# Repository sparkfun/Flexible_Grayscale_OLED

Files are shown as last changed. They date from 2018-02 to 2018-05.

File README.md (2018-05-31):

SparkFun Flexible Grayscale OLED Display Breakout Board
========================================

SparkFun Flexible Grayscale Carrier Board

[*SparkFun Flexible Grayscale Display - 1.81" (LCD-14606)*](https://www.sparkfun.com/products/14606)

This is a small flexible, grayscale OLED display. That’s right, we said flexible. We’ve been hearing about flexible displays for years, it’s finally here! You can’t fold it like paper but this OLED from Wisechip can be bent to a 40mm radius without damage. The display is than 0.5mm thick, less than 0.5 grams, and can display some impressive graphics with great contrast.

The carrier board generates the 12V required to drive the OLED display. The carrier board also has a signal buffer so that you can drive the display from any 3.3V or 5V microcontroller. However, because of the nature of the TXB0104 you must power the board with 3.5V or more. Your microcontroller can be 3.3V or 5V but we recommend you power the carrier board with 5V.

Repository Contents
-------------------

* **/Datasheets** - Datasheets explaining screen characteristics
* **/Hardware** - Eagle design files (.brd, .sch)
* **/Production** - Test bed files and production panel files.

Documentation
--------------
* **[Arduino Library](https://github.com/sparkfun/SparkFun_SSD1320_OLED_Arduino_Library)** - Arduino library for drawing, graphics, text, etc.
* **[BMP to Array](https://github.com/sparkfun/BMPtoArray)** - Python script to convert bitmaps to an Arduino prog_mem array when outputting grayscale images to OLEDs.
* **[Hookup Guide](https://learn.sparkfun.com/tutorials/flexible-grayscale-oled-hookup-guide)** - Basic hookup guide for the SparkFun Flexible Grayscale OLED Display.

License Information
-------------------

This product is _**open source**_! 

Please review the LICENSE.md file for license information. 

If you have any questions or concerns on licensing, please contact techsupport@sparkfun.com.

Please use, reuse, and modify these files as you see fit. Please maintain attribution to SparkFun Electronics and release anyThing Development Board derivative under the same license.

Distributed as-is; no warranty is given.

- Your friends at SparkFun.

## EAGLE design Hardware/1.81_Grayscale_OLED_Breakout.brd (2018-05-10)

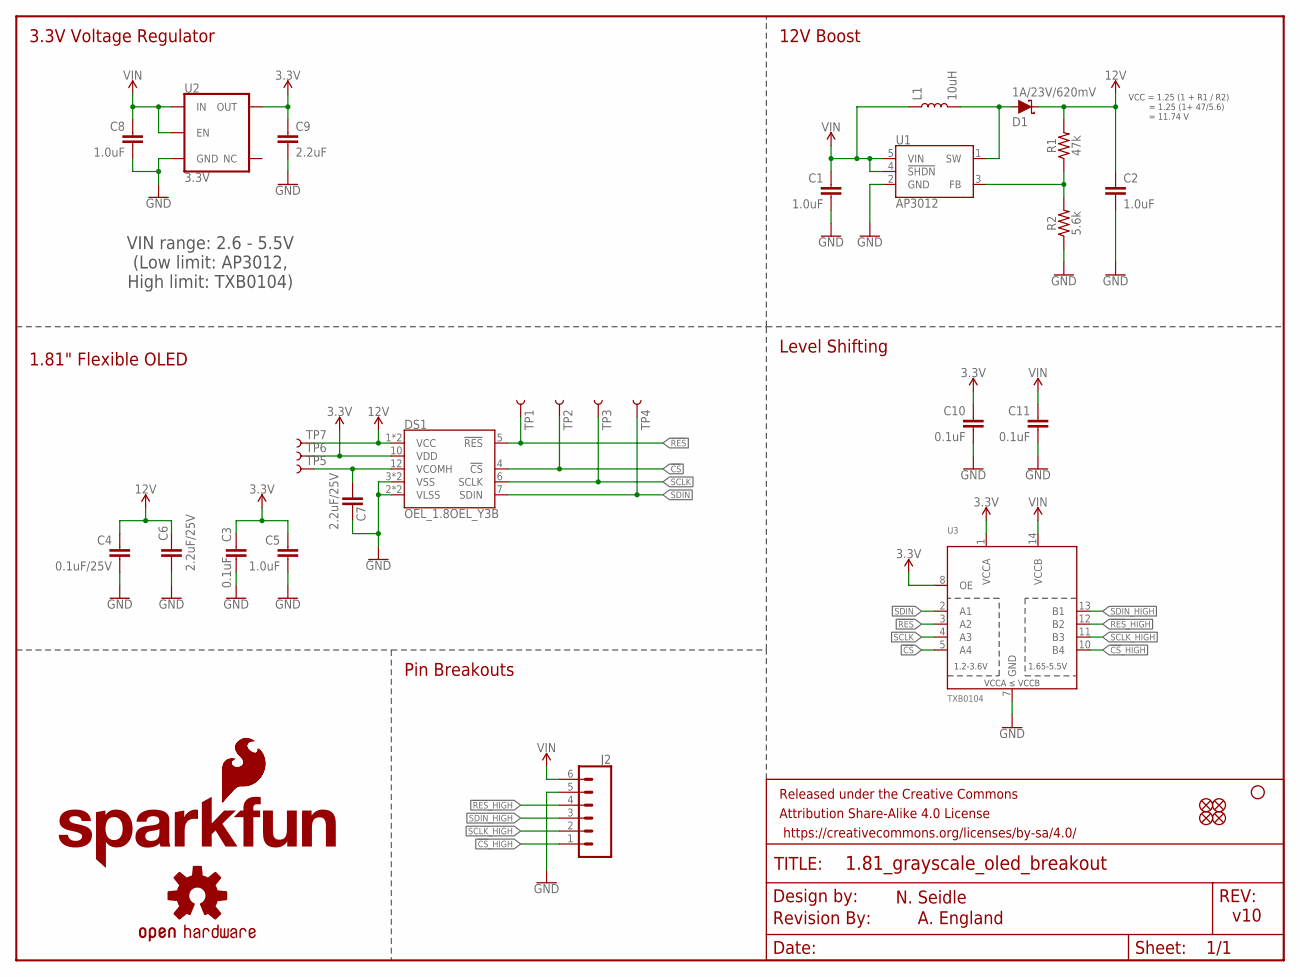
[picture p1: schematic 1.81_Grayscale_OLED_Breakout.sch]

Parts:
C1, C5, C8: 1.0uF; 0603
C2: 1.0uF; 0805
C3, C10, C11: 0.1uF; 0603
C4: 0.1uF/25V; 0603
C6, C7: 2.2uF/25V; 0805
C9: 2.2uF; 0603
D1: 1A/23V/620mV; SOD-323
DS1: OEL_1.8OEL_Y3B; OEL_1.8_FPC_Y3B
FD1, FD2, FD3, FD4: FIDUCIAL1X2; FIDUCIAL-1X2
FRAME1: FRAME-LETTER; CREATIVE_COMMONS
H2: STAND-OFF
J2: CONN_06NO_SILK_NO_POP; 1X06_NO_SILK
L1: 10uH; INDUCTOR_4.7UH
LOGO1: SFE_LOGO_NAME_FLAME.1_INCH; SFE_LOGO_NAME_FLAME_.1
LOGO2: REVISION
LOGO3: SFE_LOGO_FLAME.1_INCH; SFE_LOGO_FLAME_.1
LOGO4: OSHW-LOGOS; OSHW-LOGO-S
R1: 47k; 0603
R2: 5.6k; 0603
TP1, TP2, TP3, TP4, TP5, TP6, TP7: TEST-POINT3; PAD.03X.03
U1: AP3012; SOT23-5
U2: 3.3V; SOT23-5
U3: TXB0104; SO14

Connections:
3.3V: C3.1, C5.1, C9.1, C10.1, DS1.10 (VDD), TP6.P$1, U2.5 (OUT), U3.1 (VCCA), U3.8 (OE)
12V: C2.1, C4.1, C6.1, D1.C, DS1.1 (VCC), DS1.13 (VCC), R1.2, TP7.P$1
!CS!: DS1.4 (!CS!), TP2.P$1, U3.5 (A4)
!CS!_HIGH: J2.1, U3.10 (B4)
!RES!: DS1.5 (!RES!), TP1.P$1, U3.3 (A2)
!RES!_HIGH: J2.4, U3.12 (B2)
GND: C1.2, C2.2, C3.2, C4.2, C5.2, C6.2, C7.1, C8.2, C9.2, C10.2, C11.2, DS1.2 (VLSS), DS1.3 (VSS), DS1.8 (VSS), DS1.9 (VLSS), J2.5, R2.1, U1.2 (GND), U2.2 (GND), U3.7 (GND)
unnamed: C7.2, DS1.12 (VCOMH), TP5.P$1
unnamed: D1.A, L1.P$2 (2), U1.1 (SW)
unnamed: R1.1, R2.2, U1.3 (FB)
SCLK: DS1.6 (SCLK), TP3.P$1, U3.4 (A3)
SCLK_HIGH: J2.2, U3.11 (B3)
SDIN: DS1.7 (SDIN), TP4.P$1, U3.2 (A1)
SDIN_HIGH: J2.3, U3.13 (B1)
VIN: C1.1, C8.1, C11.1, J2.6, L1.P$1 (1), U1.4 (!SHDN!), U1.5 (VIN), U2.1 (IN), U2.3 (EN), U3.14 (VCCB)

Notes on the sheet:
VCC = 1.25 (1 + R1 / R2) = 1.25 (1+ 47/5.6) = 11.74 V
VIN range: 2.6 - 5.5V (Low limit: AP3012, High limit: TXB0104)
3.3V Voltage Regulator
12V Boost
1.81" Flexible OLED
Level Shifting
Pin Breakouts
v10
N. Seidle
A. England

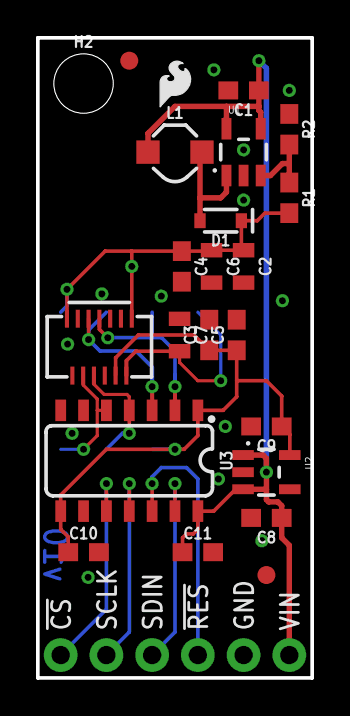
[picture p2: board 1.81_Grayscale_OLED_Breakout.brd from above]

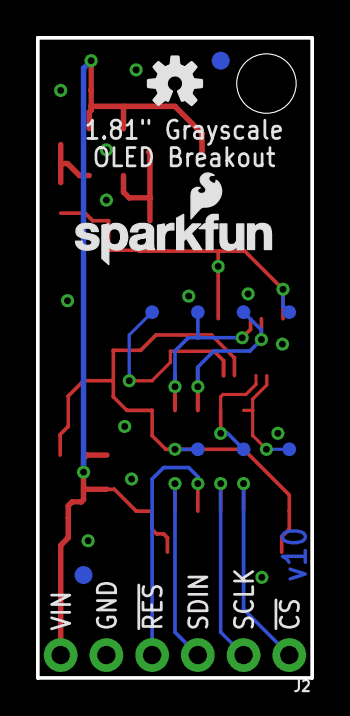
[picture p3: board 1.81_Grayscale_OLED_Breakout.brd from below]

Board: 2 copper layers, 15.2 x 35.6 mm, 37 parts (13 on the bottom side), 15 nets.

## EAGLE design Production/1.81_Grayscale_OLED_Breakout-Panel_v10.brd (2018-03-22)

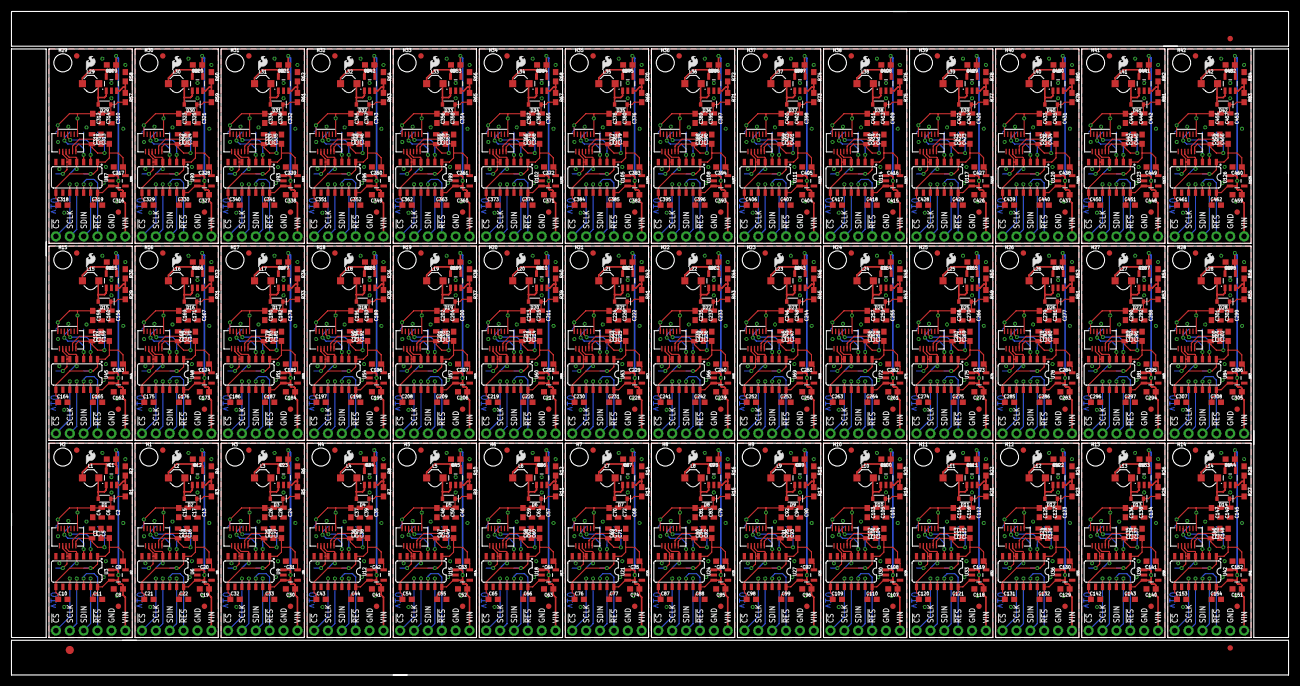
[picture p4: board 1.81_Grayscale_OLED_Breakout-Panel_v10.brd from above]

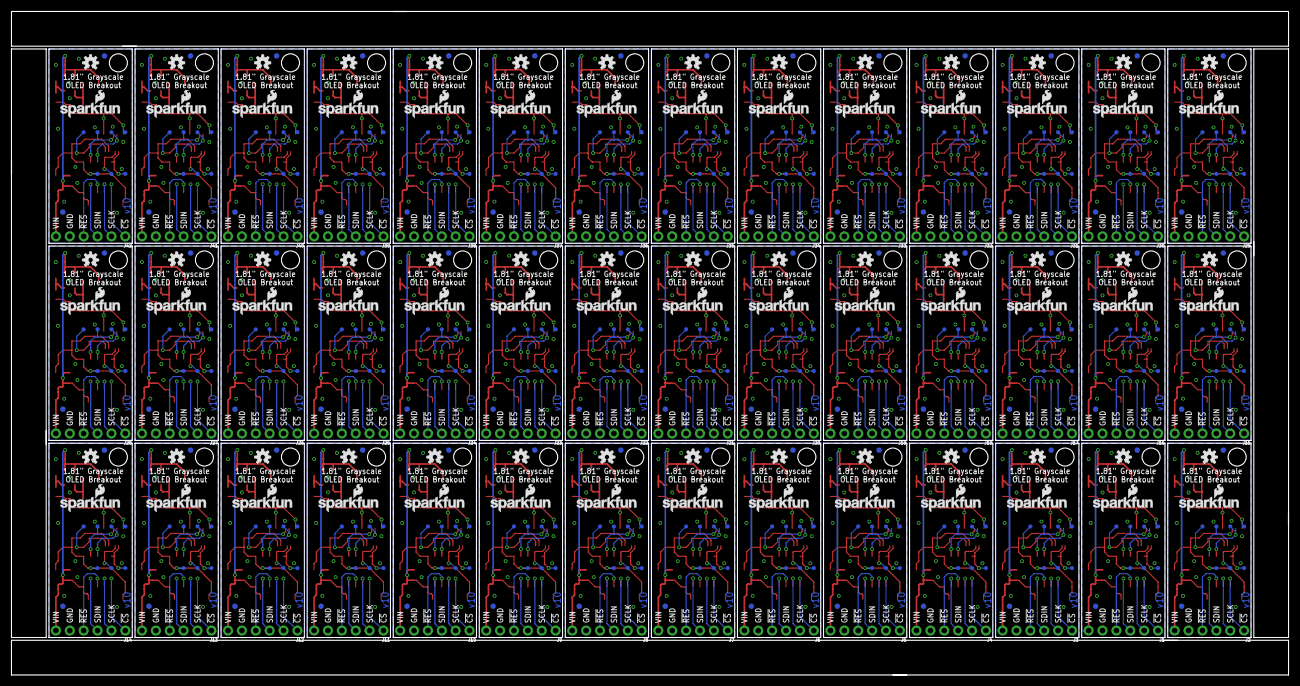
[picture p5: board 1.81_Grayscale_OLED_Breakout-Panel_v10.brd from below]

Board: 2 copper layers, 233.7 x 121.4 mm, 1473 parts (546 on the bottom side), 630 nets.

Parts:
C1, C5, C8, C12, C16, C19, C23, C27, C30, C34, C38, C41, C45, C49, C52, C56, C60, C63, C67, C71, C74, C78, C82, C85, C89, C93, C96, C100, C104, C107, C111, C115, C118, C122, C126, C129, C133, C137, C140, C144, C148, C151, C155, C159, C162, C166, C170, C173, C177, C181, C184, C188, C192, C195, C199, C203, C206, C210, C214, C217, C221, C225, C228, C232, C236, C239, C243, C247, C250, C254, C258, C261, C265, C269, C272, C276, C280, C283, C287, C291, C294, C298, C302, C305, C309, C313, C316, C320, C324, C327, C331, C335, C338, C342, C346, C349, C353, C357, C360, C364, C368, C371, C375, C379, C382, C386, C390, C393, C397, C401, C404, C408, C412, C415, C419, C423, C426, C430, C434, C437, C441, C445, C448, C452, C456, C459: 1.0uF; 0603
C2, C13, C24, C35, C46, C57, C68, C79, C90, C101, C112, C123, C134, C145, C156, C167, C178, C189, C200, C211, C222, C233, C244, C255, C266, C277, C288, C299, C310, C321, C332, C343, C354, C365, C376, C387, C398, C409, C420, C431, C442, C453: 1.0uF; 0805
C3, C10, C11, C14, C21, C22, C25, C32, C33, C36, C43, C44, C47, C54, C55, C58, C65, C66, C69, C76, C77, C80, C87, C88, C91, C98, C99, C102, C109, C110, C113, C120, C121, C124, C131, C132, C135, C142, C143, C146, C153, C154, C157, C164, C165, C168, C175, C176, C179, C186, C187, C190, C197, C198, C201, C208, C209, C212, C219, C220, C223, C230, C231, C234, C241, C242, C245, C252, C253, C256, C263, C264, C267, C274, C275, C278, C285, C286, C289, C296, C297, C300, C307, C308, C311, C318, C319, C322, C329, C330, C333, C340, C341, C344, C351, C352, C355, C362, C363, C366, C373, C374, C377, C384, C385, C388, C395, C396, C399, C406, C407, C410, C417, C418, C421, C428, C429, C432, C439, C440, C443, C450, C451, C454, C461, C462: 0.1uF; 0603
C4, C15, C26, C37, C48, C59, C70, C81, C92, C103, C114, C125, C136, C147, C158, C169, C180, C191, C202, C213, C224, C235, C246, C257, C268, C279, C290, C301, C312, C323, C334, C345, C356, C367, C378, C389, C400, C411, C422, C433, C444, C455: 0.1uF/25V; 0603
C6, C7, C17, C18, C28, C29, C39, C40, C50, C51, C61, C62, C72, C73, C83, C84, C94, C95, C105, C106, C116, C117, C127, C128, C138, C139, C149, C150, C160, C161, C171, C172, C182, C183, C193, C194, C204, C205, C215, C216, C226, C227, C237, C238, C248, C249, C259, C260, C270, C271, C281, C282, C292, C293, C303, C304, C314, C315, C325, C326, C336, C337, C347, C348, C358, C359, C369, C370, C380, C381, C391, C392, C402, C403, C413, C414, C424, C425, C435, C436, C446, C447, C457, C458: 2.2uF/25V; 0805
C9, C20, C31, C42, C53, C64, C75, C86, C97, C108, C119, C130, C141, C152, C163, C174, C185, C196, C207, C218, C229, C240, C251, C262, C273, C284, C295, C306, C317, C328, C339, C350, C361, C372, C383, C394, C405, C416, C427, C438, C449, C460: 2.2uF; 0603
D1, D2, D3, D4, D5, D6, D7, D8, D9, D10, D11, D12, D13, D14, D15, D16, D17, D18, D19, D20, D21, D22, D23, D24, D25, D26, D27, D28, D29, D30, D31, D32, D33, D34, D35, D36, D37, D38, D39, D40, D41, D42: 1A/23V/620mV; SOD-323
DS1, DS2, DS3, DS4, DS5, DS6, DS7, DS8, DS9, DS10, DS11, DS12, DS13, DS14, DS15, DS16, DS17, DS18, DS19, DS20, DS21, DS22, DS23, DS24, DS25, DS26, DS27, DS28, DS29, DS30, DS31, DS32, DS33, DS34, DS35, DS36, DS37, DS38, DS39, DS40, DS41, DS42: OEL_1.8OEL_Y3B; OEL_1.8_FPC_Y3B
E$1: FIDUCIAL-1.5X3
E$5, E$6: FIDUCIAL-1X2
FD1, FD2, FD3, FD4, FD5, FD6, FD7, FD8, FD9, FD10, FD11, FD12, FD13, FD14, FD15, FD16, FD17, FD18, FD19, FD20, FD21, FD22, FD23, FD24, FD25, FD26, FD27, FD28, FD29, FD30, FD31, FD32, FD33, FD34, FD35, FD36, FD37, FD38, FD39, FD40, FD41, FD42, FD43, FD44, FD45, FD46, FD47, FD48, FD49, FD50, FD51, FD52, FD53, FD54, FD55, FD56, FD57, FD58, FD59, FD60, FD61, FD62, FD63, FD64, FD65, FD66, FD67, FD68, FD69, FD70, FD71, FD72, FD73, FD74, FD75, FD76, FD77, FD78, FD79, FD80, FD81, FD82, FD83, FD84, FD85, FD86, FD87, FD88, FD89, FD90, FD91, FD92, FD93, FD94, FD95, FD96, FD97, FD98, FD99, FD100, FD101, FD102, FD103, FD104, FD105, FD106, FD107, FD108, FD109, FD110, FD111, FD112, FD113, FD114, FD115, FD116, FD117, FD118, FD119, FD120, FD121, FD122, FD123, FD124, FD125, FD126, FD127, FD128, FD129, FD130, FD131, FD132, FD133, FD134, FD135, FD136, FD137, FD138, FD139, FD140, FD141, FD142, FD143, FD144, FD145, FD146, FD147, FD148, FD149, FD150, FD151, FD152, FD153, FD154, FD155, FD156, FD157, FD158, FD159, FD160, FD161, FD162, FD163, FD164, FD165, FD166, FD167, FD168: FIDUCIAL1X2; FIDUCIAL-1X2
H1, H2, H3, H4, H5, H6, H7, H8, H9, H10, H11, H12, H13, H14, H15, H16, H17, H18, H19, H20, H21, H22, H23, H24, H25, H26, H27, H28, H29, H30, H31, H32, H33, H34, H35, H36, H37, H38, H39, H40, H41, H42: STAND-OFF
J1, J2, J3, J4, J5, J6, J7, J8, J9, J10, J11, J12, J13, J14, J15, J16, J17, J18, J19, J20, J21, J22, J23, J24, J25, J26, J27, J28, J29, J30, J31, J32, J33, J34, J35, J36, J37, J38, J39, J40, J41, J42: 1X06_NO_SILK
L1, L2, L3, L4, L5, L6, L7, L8, L9, L10, L11, L12, L13, L14, L15, L16, L17, L18, L19, L20, L21, L22, L23, L24, L25, L26, L27, L28, L29, L30, L31, L32, L33, L34, L35, L36, L37, L38, L39, L40, L41, L42: 10uH; INDUCTOR_4.7UH
LOGO1, LOGO2, LOGO7, LOGO10, LOGO13, LOGO16, LOGO19, LOGO22, LOGO25, LOGO28, LOGO31, LOGO34, LOGO37, LOGO40, LOGO43, LOGO46, LOGO49, LOGO52, LOGO55, LOGO58, LOGO61, LOGO64, LOGO67, LOGO70, LOGO73, LOGO76, LOGO79, LOGO82, LOGO85, LOGO88, LOGO91, LOGO94, LOGO97, LOGO100, LOGO103, LOGO106, LOGO109, LOGO112, LOGO115, LOGO118, LOGO121, LOGO124: SFE_LOGO_NAME_FLAME.1_INCH; SFE_LOGO_NAME_FLAME_.1
LOGO3, LOGO5, LOGO8, LOGO11, LOGO14, LOGO17, LOGO20, LOGO23, LOGO26, LOGO29, LOGO32, LOGO35, LOGO38, LOGO41, LOGO44, LOGO47, LOGO50, LOGO53, LOGO56, LOGO59, LOGO62, LOGO65, LOGO68, LOGO71, LOGO74, LOGO77, LOGO80, LOGO83, LOGO86, LOGO89, LOGO92, LOGO95, LOGO98, LOGO101, LOGO104, LOGO107, LOGO110, LOGO113, LOGO116, LOGO119, LOGO122, LOGO125: SFE_LOGO_FLAME.1_INCH; SFE_LOGO_FLAME_.1
LOGO4, LOGO6, LOGO9, LOGO12, LOGO15, LOGO18, LOGO21, LOGO24, LOGO27, LOGO30, LOGO33, LOGO36, LOGO39, LOGO42, LOGO45, LOGO48, LOGO51, LOGO54, LOGO57, LOGO60, LOGO63, LOGO66, LOGO69, LOGO72, LOGO75, LOGO78, LOGO81, LOGO84, LOGO87, LOGO90, LOGO93, LOGO96, LOGO99, LOGO102, LOGO105, LOGO108, LOGO111, LOGO114, LOGO117, LOGO120, LOGO123, LOGO126: OSHW-LOGOS; OSHW-LOGO-S
R1, R3, R5, R7, R9, R11, R13, R15, R17, R19, R21, R23, R25, R27, R29, R31, R33, R35, R37, R39, R41, R43, R45, R47, R49, R51, R53, R55, R57, R59, R61, R63, R65, R67, R69, R71, R73, R75, R77, R79, R81, R83: 47k; 0603
R2, R4, R6, R8, R10, R12, R14, R16, R18, R20, R22, R24, R26, R28, R30, R32, R34, R36, R38, R40, R42, R44, R46, R48, R50, R52, R54, R56, R58, R60, R62, R64, R66, R68, R70, R72, R74, R76, R78, R80, R82, R84: 5.6k; 0603
TP1, TP2, TP3, TP4, TP5, TP6, TP7, TP8, TP9, TP10, TP11, TP12, TP13, TP14, TP15, TP16, TP17, TP18, TP19, TP20, TP21, TP22, TP23, TP24, TP25, TP26, TP27, TP28, TP29, TP30, TP31, TP32, TP33, TP34, TP35, TP36, TP37, TP38, TP39, TP40, TP41, TP42, TP43, TP44, TP45, TP46, TP47, TP48, TP49, TP50, TP51, TP52, TP53, TP54, TP55, TP56, TP57, TP58, TP59, TP60, TP61, TP62, TP63, TP64, TP65, TP66, TP67, TP68, TP69, TP70, TP71, TP72, TP73, TP74, TP75, TP76, TP77, TP78, TP79, TP80, TP81, TP82, TP83, TP84, TP85, TP86, TP87, TP88, TP89, TP90, TP91, TP92, TP93, TP94, TP95, TP96, TP97, TP98, TP99, TP100, TP101, TP102, TP103, TP104, TP105, TP106, TP107, TP108, TP109, TP110, TP111, TP112, TP113, TP114, TP115, TP116, TP117, TP118, TP119, TP120, TP121, TP122, TP123, TP124, TP125, TP126, TP127, TP128, TP129, TP130, TP131, TP132, TP133, TP134, TP135, TP136, TP137, TP138, TP139, TP140, TP141, TP142, TP143, TP144, TP145, TP146, TP147, TP148, TP149, TP150, TP151, TP152, TP153, TP154, TP155, TP156, TP157, TP158, TP159, TP160, TP161, TP162, TP163, TP164, TP165, TP166, TP167, TP168, TP169, TP170, TP171, TP172, TP173, TP174, TP175, TP176, TP177, TP178, TP179, TP180, TP181, TP182, TP183, TP184, TP185, TP186, TP187, TP188, TP189, TP190, TP191, TP192, TP193, TP194, TP195, TP196, TP197, TP198, TP199, TP200, TP201, TP202, TP203, TP204, TP205, TP206, TP207, TP208, TP209, TP210, TP211, TP212, TP213, TP214, TP215, TP216, TP217, TP218, TP219, TP220, TP221, TP222, TP223, TP224, TP225, TP226, TP227, TP228, TP229, TP230, TP231, TP232, TP233, TP234, TP235, TP236, TP237, TP238, TP239, TP240, TP241, TP242, TP243, TP244, TP245, TP246, TP247, TP248, TP249, TP250, TP251, TP252, TP253, TP254, TP255, TP256, TP257, TP258, TP259, TP260, TP261, TP262, TP263, TP264, TP265, TP266, TP267, TP268, TP269, TP270, TP271, TP272, TP273, TP274, TP275, TP276, TP277, TP278, TP279, TP280, TP281, TP282, TP283, TP284, TP285, TP286, TP287, TP288, TP289, TP290, TP291, TP292, TP293, TP294: TEST-POINT3; PAD.03X.03
U1, U4, U7, U10, U13, U16, U19, U22, U25, U28, U31, U34, U37, U40, U43, U46, U49, U52, U55, U58, U61, U64, U67, U70, U73, U76, U79, U82, U85, U88, U91, U94, U97, U100, U103, U106, U109, U112, U115, U118, U121, U124: AP3012; SOT23-5
U2, U5, U8, U11, U14, U17, U20, U23, U26, U29, U32, U35, U38, U41, U44, U47, U50, U53, U56, U59, U62, U65, U68, U71, U74, U77, U80, U83, U86, U89, U92, U95, U98, U101, U104, U107, U110, U113, U116, U119, U122, U125: 3.3V; SOT23-5
U3, U6, U9, U12, U15, U18, U21, U24, U27, U30, U33, U36, U39, U42, U45, U48, U51, U54, U57, U60, U63, U66, U69, U72, U75, U78, U81, U84, U87, U90, U93, U96, U99, U102, U105, U108, U111, U114, U117, U120, U123, U126: TXB0104; SO14

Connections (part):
3.3V: C3.1, C5.1, C9.1, C10.1, DS1.10, TP6.P$1, U2.5, U3.1, U3.8
3.3V1: C14.1, C16.1, C20.1, C21.1, DS2.10, TP13.P$1, U5.5, U6.1, U6.8
3.3V2: C25.1, C27.1, C31.1, C32.1, DS3.10, TP20.P$1, U8.5, U9.1, U9.8
3.3V3: C36.1, C38.1, C42.1, C43.1, DS4.10, TP27.P$1, U11.5, U12.1, U12.8
3.3V4: C47.1, C49.1, C53.1, C54.1, DS5.10, TP34.P$1, U14.5, U15.1, U15.8
3.3V5: C58.1, C60.1, C64.1, C65.1, DS6.10, TP41.P$1, U17.5, U18.1, U18.8
3.3V6: C69.1, C71.1, C75.1, C76.1, DS7.10, TP48.P$1, U20.5, U21.1, U21.8
3.3V7: C80.1, C82.1, C86.1, C87.1, DS8.10, TP55.P$1, U23.5, U24.1, U24.8
3.3V8: C91.1, C93.1, C97.1, C98.1, DS9.10, TP62.P$1, U26.5, U27.1, U27.8
3.3V9: C102.1, C104.1, C108.1, C109.1, DS10.10, TP69.P$1, U29.5, U30.1, U30.8
3.3V10: C113.1, C115.1, C119.1, C120.1, DS11.10, TP76.P$1, U32.5, U33.1, U33.8
3.3V11: C124.1, C126.1, C130.1, C131.1, DS12.10, TP83.P$1, U35.5, U36.1, U36.8
3.3V12: C135.1, C137.1, C141.1, C142.1, DS13.10, TP90.P$1, U38.5, U39.1, U39.8
3.3V13: C146.1, C148.1, C152.1, C153.1, DS14.10, TP97.P$1, U41.5, U42.1, U42.8
3.3V14: C157.1, C159.1, C163.1, C164.1, DS15.10, TP104.P$1, U44.5, U45.1, U45.8
3.3V15: C168.1, C170.1, C174.1, C175.1, DS16.10, TP111.P$1, U47.5, U48.1, U48.8
3.3V16: C179.1, C181.1, C185.1, C186.1, DS17.10, TP118.P$1, U50.5, U51.1, U51.8
3.3V17: C190.1, C192.1, C196.1, C197.1, DS18.10, TP125.P$1, U53.5, U54.1, U54.8
3.3V18: C201.1, C203.1, C207.1, C208.1, DS19.10, TP132.P$1, U56.5, U57.1, U57.8
3.3V19: C212.1, C214.1, C218.1, C219.1, DS20.10, TP139.P$1, U59.5, U60.1, U60.8
3.3V20: C223.1, C225.1, C229.1, C230.1, DS21.10, TP146.P$1, U62.5, U63.1, U63.8
3.3V21: C234.1, C236.1, C240.1, C241.1, DS22.10, TP153.P$1, U65.5, U66.1, U66.8
3.3V22: C245.1, C247.1, C251.1, C252.1, DS23.10, TP160.P$1, U68.5, U69.1, U69.8
3.3V23: C256.1, C258.1, C262.1, C263.1, DS24.10, TP167.P$1, U71.5, U72.1, U72.8
3.3V24: C267.1, C269.1, C273.1, C274.1, DS25.10, TP174.P$1, U74.5, U75.1, U75.8
3.3V25: C278.1, C280.1, C284.1, C285.1, DS26.10, TP181.P$1, U77.5, U78.1, U78.8
3.3V26: C289.1, C291.1, C295.1, C296.1, DS27.10, TP188.P$1, U80.5, U81.1, U81.8
3.3V27: C300.1, C302.1, C306.1, C307.1, DS28.10, TP195.P$1, U83.5, U84.1, U84.8
3.3V28: C311.1, C313.1, C317.1, C318.1, DS29.10, TP202.P$1, U86.5, U87.1, U87.8
3.3V29: C322.1, C324.1, C328.1, C329.1, DS30.10, TP209.P$1, U89.5, U90.1, U90.8
3.3V30: C333.1, C335.1, C339.1, C340.1, DS31.10, TP216.P$1, U92.5, U93.1, U93.8
3.3V31: C344.1, C346.1, C350.1, C351.1, DS32.10, TP223.P$1, U95.5, U96.1, U96.8
3.3V32: C355.1, C357.1, C361.1, C362.1, DS33.10, TP230.P$1, U98.5, U99.1, U99.8
3.3V33: C366.1, C368.1, C372.1, C373.1, DS34.10, TP237.P$1, U101.5, U102.1, U102.8
3.3V34: C377.1, C379.1, C383.1, C384.1, DS35.10, TP244.P$1, U104.5, U105.1, U105.8
3.3V35: C388.1, C390.1, C394.1, C395.1, DS36.10, TP251.P$1, U107.5, U108.1, U108.8
3.3V36: C399.1, C401.1, C405.1, C406.1, DS37.10, TP258.P$1, U110.5, U111.1, U111.8
3.3V37: C410.1, C412.1, C416.1, C417.1, DS38.10, TP265.P$1, U113.5, U114.1, U114.8
3.3V38: C421.1, C423.1, C427.1, C428.1, DS39.10, TP272.P$1, U116.5, U117.1, U117.8
3.3V39: C432.1, C434.1, C438.1, C439.1, DS40.10, TP279.P$1, U119.5, U120.1, U120.8
3.3V40: C443.1, C445.1, C449.1, C450.1, DS41.10, TP286.P$1, U122.5, U123.1, U123.8
3.3V41: C454.1, C456.1, C460.1, C461.1, DS42.10, TP293.P$1, U125.5, U126.1, U126.8
12V: C2.1, C4.1, C6.1, D1.C, DS1.1, DS1.13, R1.2, TP7.P$1
12V1: C13.1, C15.1, C17.1, D2.C, DS2.1, DS2.13, R3.2, TP14.P$1
12V2: C24.1, C26.1, C28.1, D3.C, DS3.1, DS3.13, R5.2, TP21.P$1
12V3: C35.1, C37.1, C39.1, D4.C, DS4.1, DS4.13, R7.2, TP28.P$1
12V4: C46.1, C48.1, C50.1, D5.C, DS5.1, DS5.13, R9.2, TP35.P$1
12V5: C57.1, C59.1, C61.1, D6.C, DS6.1, DS6.13, R11.2, TP42.P$1
12V6: C68.1, C70.1, C72.1, D7.C, DS7.1, DS7.13, R13.2, TP49.P$1
12V7: C79.1, C81.1, C83.1, D8.C, DS8.1, DS8.13, R15.2, TP56.P$1
12V8: C90.1, C92.1, C94.1, D9.C, DS9.1, DS9.13, R17.2, TP63.P$1
12V9: C101.1, C103.1, C105.1, D10.C, DS10.1, DS10.13, R19.2, TP70.P$1
12V10: C112.1, C114.1, C116.1, D11.C, DS11.1, DS11.13, R21.2, TP77.P$1
12V11: C123.1, C125.1, C127.1, D12.C, DS12.1, DS12.13, R23.2, TP84.P$1
12V12: C134.1, C136.1, C138.1, D13.C, DS13.1, DS13.13, R25.2, TP91.P$1
12V13: C145.1, C147.1, C149.1, D14.C, DS14.1, DS14.13, R27.2, TP98.P$1
12V14: C156.1, C158.1, C160.1, D15.C, DS15.1, DS15.13, R29.2, TP105.P$1
12V15: C167.1, C169.1, C171.1, D16.C, DS16.1, DS16.13, R31.2, TP112.P$1
12V16: C178.1, C180.1, C182.1, D17.C, DS17.1, DS17.13, R33.2, TP119.P$1
12V17: C189.1, C191.1, C193.1, D18.C, DS18.1, DS18.13, R35.2, TP126.P$1
12V18: C200.1, C202.1, C204.1, D19.C, DS19.1, DS19.13, R37.2, TP133.P$1
12V19: C211.1, C213.1, C215.1, D20.C, DS20.1, DS20.13, R39.2, TP140.P$1
12V20: C222.1, C224.1, C226.1, D21.C, DS21.1, DS21.13, R41.2, TP147.P$1
12V21: C233.1, C235.1, C237.1, D22.C, DS22.1, DS22.13, R43.2, TP154.P$1
12V22: C244.1, C246.1, C248.1, D23.C, DS23.1, DS23.13, R45.2, TP161.P$1
12V23: C255.1, C257.1, C259.1, D24.C, DS24.1, DS24.13, R47.2, TP168.P$1
12V24: C266.1, C268.1, C270.1, D25.C, DS25.1, DS25.13, R49.2, TP175.P$1
12V25: C277.1, C279.1, C281.1, D26.C, DS26.1, DS26.13, R51.2, TP182.P$1
12V26: C288.1, C290.1, C292.1, D27.C, DS27.1, DS27.13, R53.2, TP189.P$1
12V27: C299.1, C301.1, C303.1, D28.C, DS28.1, DS28.13, R55.2, TP196.P$1
12V28: C310.1, C312.1, C314.1, D29.C, DS29.1, DS29.13, R57.2, TP203.P$1
12V29: C321.1, C323.1, C325.1, D30.C, DS30.1, DS30.13, R59.2, TP210.P$1
12V30: C332.1, C334.1, C336.1, D31.C, DS31.1, DS31.13, R61.2, TP217.P$1
12V31: C343.1, C345.1, C347.1, D32.C, DS32.1, DS32.13, R63.2, TP224.P$1
12V32: C354.1, C356.1, C358.1, D33.C, DS33.1, DS33.13, R65.2, TP231.P$1
12V33: C365.1, C367.1, C369.1, D34.C, DS34.1, DS34.13, R67.2, TP238.P$1
12V34: C376.1, C378.1, C380.1, D35.C, DS35.1, DS35.13, R69.2, TP245.P$1
12V35: C387.1, C389.1, C391.1, D36.C, DS36.1, DS36.13, R71.2, TP252.P$1
12V36: C398.1, C400.1, C402.1, D37.C, DS37.1, DS37.13, R73.2, TP259.P$1
12V37: C409.1, C411.1, C413.1, D38.C, DS38.1, DS38.13, R75.2, TP266.P$1
12V38: C420.1, C422.1, C424.1, D39.C, DS39.1, DS39.13, R77.2, TP273.P$1
12V39: C431.1, C433.1, C435.1, D40.C, DS40.1, DS40.13, R79.2, TP280.P$1
12V40: C442.1, C444.1, C446.1, D41.C, DS41.1, DS41.13, R81.2, TP287.P$1
12V41: C453.1, C455.1, C457.1, D42.C, DS42.1, DS42.13, R83.2, TP294.P$1
!CS!: DS1.4, TP2.P$1, U3.5
!CS!1: DS2.4, TP9.P$1, U6.5
!CS!2: DS3.4, TP16.P$1, U9.5
!CS!3: DS4.4, TP23.P$1, U12.5
!CS!4: DS5.4, TP30.P$1, U15.5
!CS!5: DS6.4, TP37.P$1, U18.5
!CS!6: DS7.4, TP44.P$1, U21.5
!CS!7: DS8.4, TP51.P$1, U24.5
!CS!8: DS9.4, TP58.P$1, U27.5
!CS!9: DS10.4, TP65.P$1, U30.5
!CS!10: DS11.4, TP72.P$1, U33.5
!CS!11: DS12.4, TP79.P$1, U36.5
!CS!12: DS13.4, TP86.P$1, U39.5
!CS!13: DS14.4, TP93.P$1, U42.5
!CS!14: DS15.4, TP100.P$1, U45.5
!CS!15: DS16.4, TP107.P$1, U48.5
!CS!16: DS17.4, TP114.P$1, U51.5
!CS!17: DS18.4, TP121.P$1, U54.5
!CS!18: DS19.4, TP128.P$1, U57.5
!CS!19: DS20.4, TP135.P$1, U60.5
!CS!20: DS21.4, TP142.P$1, U63.5
!CS!21: DS22.4, TP149.P$1, U66.5
!CS!22: DS23.4, TP156.P$1, U69.5
!CS!23: DS24.4, TP163.P$1, U72.5
!CS!24: DS25.4, TP170.P$1, U75.5
!CS!25: DS26.4, TP177.P$1, U78.5
!CS!26: DS27.4, TP184.P$1, U81.5
!CS!27: DS28.4, TP191.P$1, U84.5
!CS!28: DS29.4, TP198.P$1, U87.5
!CS!29: DS30.4, TP205.P$1, U90.5
!CS!30: DS31.4, TP212.P$1, U93.5
!CS!31: DS32.4, TP219.P$1, U96.5
!CS!32: DS33.4, TP226.P$1, U99.5
!CS!33: DS34.4, TP233.P$1, U102.5
!CS!34: DS35.4, TP240.P$1, U105.5
!CS!35: DS36.4, TP247.P$1, U108.5
!CS!36: DS37.4, TP254.P$1, U111.5
!CS!37: DS38.4, TP261.P$1, U114.5
!CS!38: DS39.4, TP268.P$1, U117.5
!CS!39: DS40.4, TP275.P$1, U120.5
!CS!40: DS41.4, TP282.P$1, U123.5
!CS!41: DS42.4, TP289.P$1, U126.5
!CS!_HIGH: J2.1, U3.10
!CS!_HIGH1: J1.1, U6.10
!CS!_HIGH2: J3.1, U9.10
!CS!_HIGH3: J4.1, U12.10
!CS!_HIGH4: J5.1, U15.10
!CS!_HIGH5: J6.1, U18.10
!CS!_HIGH6: J7.1, U21.10
!CS!_HIGH7: J8.1, U24.10
!CS!_HIGH8: J9.1, U27.10
!CS!_HIGH9: J10.1, U30.10
!CS!_HIGH10: J11.1, U33.10
!CS!_HIGH11: J12.1, U36.10
!CS!_HIGH12: J13.1, U39.10
!CS!_HIGH13: J14.1, U42.10
!CS!_HIGH14: J15.1, U45.10
!CS!_HIGH15: J16.1, U48.10
!CS!_HIGH16: J17.1, U51.10
!CS!_HIGH17: J18.1, U54.10
!CS!_HIGH18: J19.1, U57.10
!CS!_HIGH19: J20.1, U60.10
!CS!_HIGH20: J21.1, U63.10
!CS!_HIGH21: J22.1, U66.10
!CS!_HIGH22: J23.1, U69.10
!CS!_HIGH23: J24.1, U72.10
!CS!_HIGH24: J25.1, U75.10
!CS!_HIGH25: J26.1, U78.10
!CS!_HIGH26: J27.1, U81.10
!CS!_HIGH27: J28.1, U84.10
!CS!_HIGH28: J29.1, U87.10
!CS!_HIGH29: J30.1, U90.10
!CS!_HIGH30: J31.1, U93.10
!CS!_HIGH31: J32.1, U96.10
!CS!_HIGH32: J33.1, U99.10
!CS!_HIGH33: J34.1, U102.10
!CS!_HIGH34: J35.1, U105.10
!CS!_HIGH35: J36.1, U108.10
!CS!_HIGH36: J37.1, U111.10
!CS!_HIGH37: J38.1, U114.10
!CS!_HIGH38: J39.1, U117.10
!CS!_HIGH39: J40.1, U120.10
!CS!_HIGH40: J41.1, U123.10
!CS!_HIGH41: J42.1, U126.10
!RES!: DS1.5, TP1.P$1, U3.3
!RES!1: DS2.5, TP8.P$1, U6.3
!RES!2: DS3.5, TP15.P$1, U9.3
!RES!3: DS4.5, TP22.P$1, U12.3
!RES!4: DS5.5, TP29.P$1, U15.3
!RES!5: DS6.5, TP36.P$1, U18.3
!RES!6: DS7.5, TP43.P$1, U21.3
!RES!7: DS8.5, TP50.P$1, U24.3
!RES!8: DS9.5, TP57.P$1, U27.3
!RES!9: DS10.5, TP64.P$1, U30.3
!RES!10: DS11.5, TP71.P$1, U33.3
!RES!11: DS12.5, TP78.P$1, U36.3
!RES!12: DS13.5, TP85.P$1, U39.3
!RES!13: DS14.5, TP92.P$1, U42.3
!RES!14: DS15.5, TP99.P$1, U45.3
!RES!15: DS16.5, TP106.P$1, U48.3
!RES!16: DS17.5, TP113.P$1, U51.3
!RES!17: DS18.5, TP120.P$1, U54.3
!RES!18: DS19.5, TP127.P$1, U57.3
!RES!19: DS20.5, TP134.P$1, U60.3
!RES!20: DS21.5, TP141.P$1, U63.3
!RES!21: DS22.5, TP148.P$1, U66.3
!RES!22: DS23.5, TP155.P$1, U69.3
!RES!23: DS24.5, TP162.P$1, U72.3
!RES!24: DS25.5, TP169.P$1, U75.3
!RES!25: DS26.5, TP176.P$1, U78.3
!RES!26: DS27.5, TP183.P$1, U81.3
!RES!27: DS28.5, TP190.P$1, U84.3
!RES!28: DS29.5, TP197.P$1, U87.3
!RES!29: DS30.5, TP204.P$1, U90.3
!RES!30: DS31.5, TP211.P$1, U93.3
!RES!31: DS32.5, TP218.P$1, U96.3
!RES!32: DS33.5, TP225.P$1, U99.3
!RES!33: DS34.5, TP232.P$1, U102.3
!RES!34: DS35.5, TP239.P$1, U105.3
!RES!35: DS36.5, TP246.P$1, U108.3
!RES!36: DS37.5, TP253.P$1, U111.3
!RES!37: DS38.5, TP260.P$1, U114.3
!RES!38: DS39.5, TP267.P$1, U117.3
!RES!39: DS40.5, TP274.P$1, U120.3
!RES!40: DS41.5, TP281.P$1, U123.3
!RES!41: DS42.5, TP288.P$1, U126.3
!RES!_HIGH: J2.4, U3.12
!RES!_HIGH1: J1.4, U6.12
!RES!_HIGH2: J3.4, U9.12
!RES!_HIGH3: J4.4, U12.12
!RES!_HIGH4: J5.4, U15.12
!RES!_HIGH5: J6.4, U18.12
!RES!_HIGH6: J7.4, U21.12
!RES!_HIGH7: J8.4, U24.12
!RES!_HIGH8: J9.4, U27.12
!RES!_HIGH9: J10.4, U30.12
!RES!_HIGH10: J11.4, U33.12
!RES!_HIGH11: J12.4, U36.12
!RES!_HIGH12: J13.4, U39.12
!RES!_HIGH13: J14.4, U42.12
!RES!_HIGH14: J15.4, U45.12
!RES!_HIGH15: J16.4, U48.12
!RES!_HIGH16: J17.4, U51.12
!RES!_HIGH17: J18.4, U54.12
!RES!_HIGH18: J19.4, U57.12
!RES!_HIGH19: J20.4, U60.12
!RES!_HIGH20: J21.4, U63.12
!RES!_HIGH21: J22.4, U66.12
!RES!_HIGH22: J23.4, U69.12
!RES!_HIGH23: J24.4, U72.12
!RES!_HIGH24: J25.4, U75.12
!RES!_HIGH25: J26.4, U78.12
!RES!_HIGH26: J27.4, U81.12
!RES!_HIGH27: J28.4, U84.12
!RES!_HIGH28: J29.4, U87.12
!RES!_HIGH29: J30.4, U90.12
!RES!_HIGH30: J31.4, U93.12
!RES!_HIGH31: J32.4, U96.12
!RES!_HIGH32: J33.4, U99.12
!RES!_HIGH33: J34.4, U102.12
!RES!_HIGH34: J35.4, U105.12
!RES!_HIGH35: J36.4, U108.12
!RES!_HIGH36: J37.4, U111.12
!RES!_HIGH37: J38.4, U114.12
!RES!_HIGH38: J39.4, U117.12
!RES!_HIGH39: J40.4, U120.12
!RES!_HIGH40: J41.4, U123.12
!RES!_HIGH41: J42.4, U126.12
GND: C1.2, C2.2, C3.2, C4.2, C5.2, C6.2, C7.1, C8.2, C9.2, C10.2, C11.2, DS1.2, DS1.3, DS1.8, DS1.9, J2.5, R2.1, U1.2, U2.2, U3.7
GND1: C12.2, C13.2, C14.2, C15.2, C16.2, C17.2, C18.1, C19.2, C20.2, C21.2, C22.2, DS2.2, DS2.3, DS2.8, DS2.9, J1.5, R4.1, U4.2, U5.2, U6.7
GND2: C23.2, C24.2, C25.2, C26.2, C27.2, C28.2, C29.1, C30.2, C31.2, C32.2, C33.2, DS3.2, DS3.3, DS3.8, DS3.9, J3.5, R6.1, U7.2, U8.2, U9.7
GND3: C34.2, C35.2, C36.2, C37.2, C38.2, C39.2, C40.1, C41.2, C42.2, C43.2, C44.2, DS4.2, DS4.3, DS4.8, DS4.9, J4.5, R8.1, U10.2, U11.2, U12.7
GND4: C45.2, C46.2, C47.2, C48.2, C49.2, C50.2, C51.1, C52.2, C53.2, C54.2, C55.2, DS5.2, DS5.3, DS5.8, DS5.9, J5.5, R10.1, U13.2, U14.2, U15.7
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

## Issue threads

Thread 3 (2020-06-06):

New display: Almost nothing visible

richardklingler, 2020-06-06:
New display arrived from Digikey....

Hooked up with Arduino Uno....only the right most vertical line is brighter...
the rest is extremely dark and isn't visible in daylight.

I assume those OLEDs don't last very long...

So stay away if you still consider buying this thing.....pretty expensive for a almost-DOA product..

nseidle, 2020-06-08:
Sounds like the driver board is working but you got a bad or damaged display. These are fragile and can be damaged if bent too far. I'm sure Digikey will help you get a replacement. If not certainly let SparkFun CS know.

Closed 2020-06-08.

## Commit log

2018-02-21 Cleaning up repo added version number
    [1.81_Greyscale_OLED_Breakout.brd, 1.81_Greyscale_OLED_Breakout.sch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]
2018-02-21 Fixed issue with multiple boards
    [1.81_Greyscale_OLED_Breakout.brd, 1.81_Greyscale_OLED_Breakout.sch]
2018-02-23 post design review/checklist changes
    [1.81_Grayscale_OLED_Breakout.brd, 1.81_Grayscale_OLED_Breakout.sch]
2018-02-23 post QC checklist changes
    [1.81_Grayscale_OLED_Breakout.brd, 1.81_Grayscale_OLED_Breakout.sch]
2018-03-08 added panel
    [1.81_Grayscale_OLED_Breakout.GBL, 1.81_Grayscale_OLED_Breakout.GBO, 1.81_Grayscale_OLED_Breakout.GBS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]
2018-03-12 post checklist changes
    [1.81_Grayscale_OLED_Breakout.brd, 1.81_Grayscale_OLED_Breakout.sch]
2018-03-22 created panel v10
    [1.81_Grayscale_OLED_Breakout-Panel_v10.brd]
2018-05-10 changed prod_id on inductor
    [1.81_Grayscale_OLED_Breakout.brd, 1.81_Grayscale_OLED_Breakout.sch]
2018-05-29 cleaned repo
    [1.81_Grayscale_OLED_Breakout.GBL, 1.81_Grayscale_OLED_Breakout.GBO, 1.81_Grayscale_OLED_Breakout.GBS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]

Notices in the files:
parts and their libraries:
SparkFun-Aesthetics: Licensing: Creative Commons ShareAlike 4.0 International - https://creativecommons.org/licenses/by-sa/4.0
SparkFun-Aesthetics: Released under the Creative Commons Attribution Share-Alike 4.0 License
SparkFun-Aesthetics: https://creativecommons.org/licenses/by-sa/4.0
